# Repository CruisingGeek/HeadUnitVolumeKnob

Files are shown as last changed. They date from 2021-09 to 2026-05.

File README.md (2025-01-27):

# HeadUnitVolumeKnob
Putting this Arduino module between your aftermarket Android head unit with a rotary encoder allows volume control via the knob. Requires 2 n-channel MOSFETs to be driven from the Arduino Pro Micro

## Hardware
This code has been written to run on an Arduino Pro Micro. It should be easy to port it to other Arduino boards.

## Dependencies
This code depends on the CruisingGeekCommon library. You can find that library here: https://github.com/CruisingGeek/CruisingGeekCommon
Unpack that library into your Arduino libraries folder.

This code also depends on a 3rd party RotoryEncoder library you can find here: https://github.com/mathertel/RotaryEncoder
Unpack this into your libraries folder as well.

## MOSFET board
If you are building this project and would like the mosfet board to switch the two external resistors, please contact me @ CruisingGeek@gmail.com

## Wiring Diagrams
The following are wiring diagrams using both the MOSFET board and for generic MOSFETs

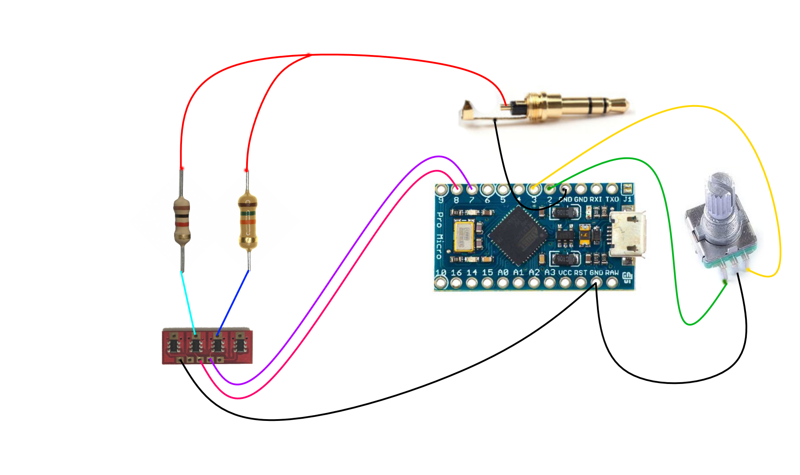
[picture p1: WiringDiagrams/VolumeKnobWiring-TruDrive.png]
Wiring diagram with TruDrive

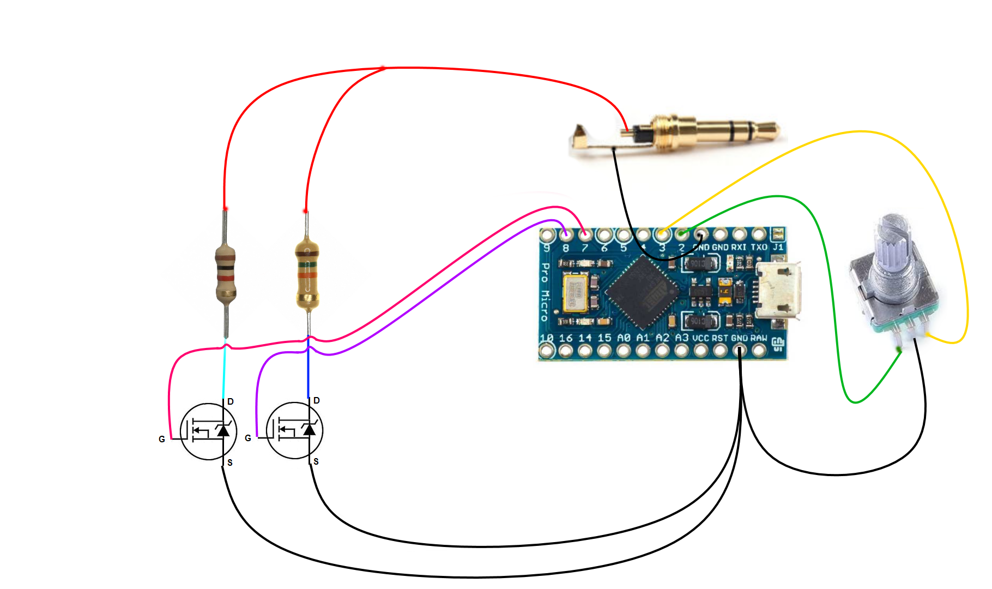
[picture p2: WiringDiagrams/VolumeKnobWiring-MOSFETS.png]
Wiring diagram with TruDrive


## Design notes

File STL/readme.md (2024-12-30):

#STL files for Atoto install
These files are the ones I used to install the Atoto S7 into my LP 560-4. It might work for other Audi cars of the 2000s era.

Use at your own risk; I'm not responsible for any issues that happen due to using these files.

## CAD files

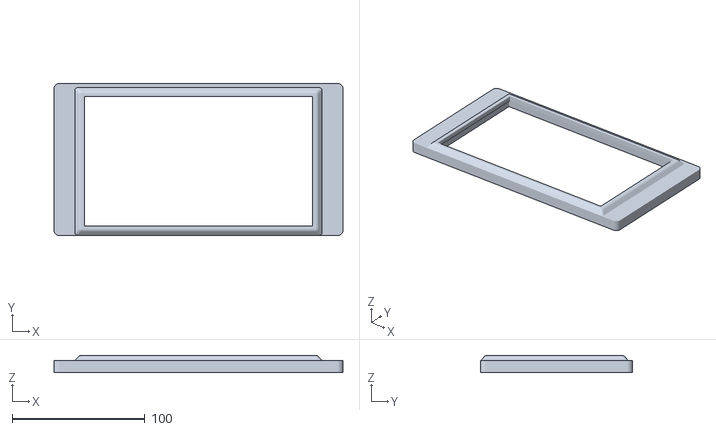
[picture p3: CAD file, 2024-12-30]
STL/Frame Full.stl
217.6 x 114.6 x 13.0

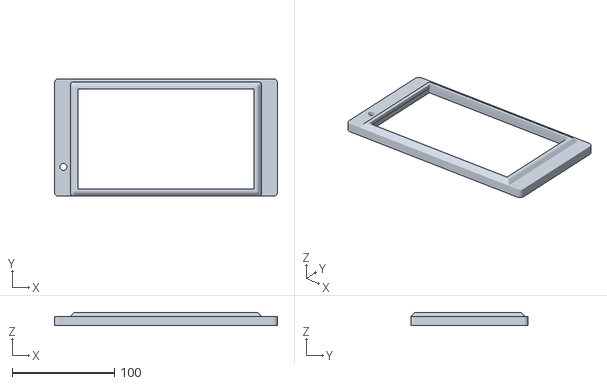
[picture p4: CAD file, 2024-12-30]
STL/Frame Full with Volume Mount.stl
217.6 x 114.6 x 13.0

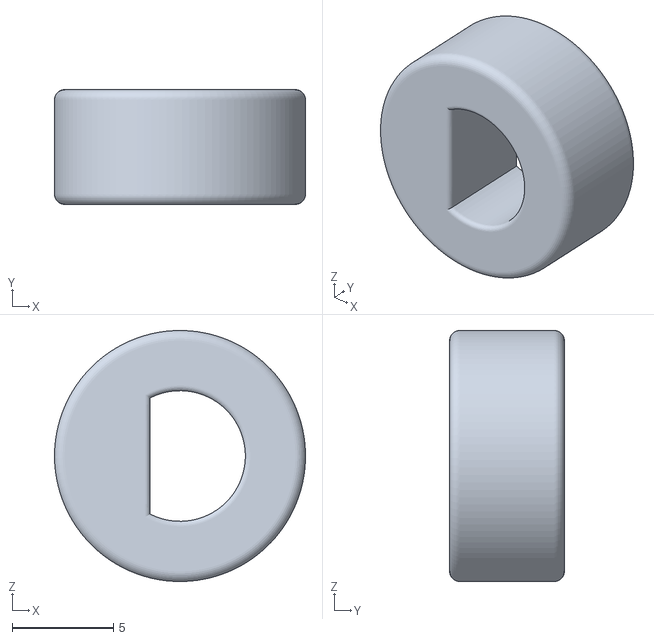
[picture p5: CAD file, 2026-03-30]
STL/Knob-StarToDShaft_revB.stl
12.4 x 5.67 x 12.4

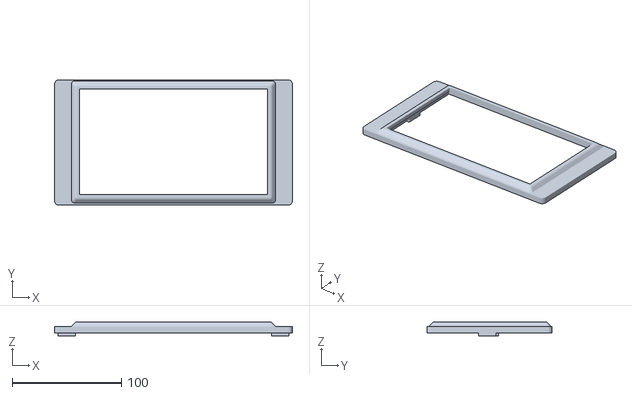
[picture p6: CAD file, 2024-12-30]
STL/Frame Slim.stl
217.6 x 114.6 x 13.0

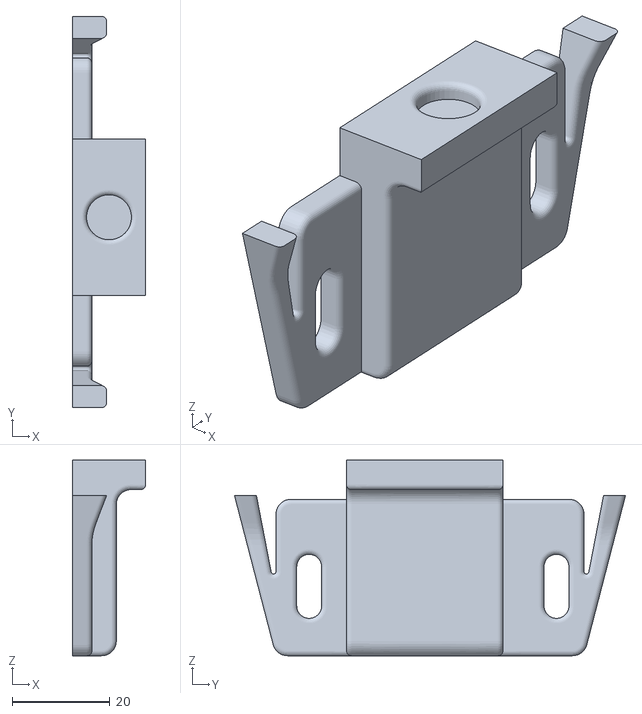
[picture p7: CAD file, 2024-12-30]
STL/Bracket R.stl
15.0 x 80.0 x 40.0

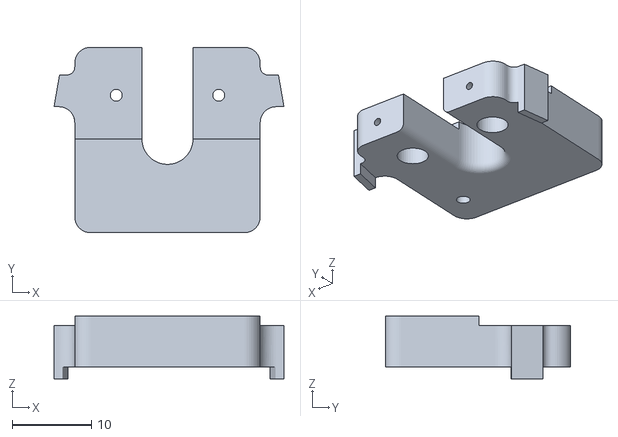
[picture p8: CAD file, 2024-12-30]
STL/Atoto Camera Adapter.stl
29.0 x 23.4 x 7.90

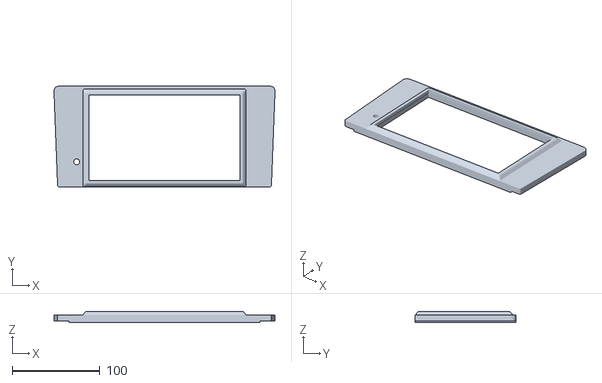
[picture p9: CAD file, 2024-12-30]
STL/Frame ALL with Volume.stl
252.1 x 115.1 x 13.0

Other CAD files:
STL/Bracket R Rev 4.stl
STL/Bracket R Rev 3.stl

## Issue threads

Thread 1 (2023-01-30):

Wiring questions

antlaranjeira, 2023-01-30:
- So the arduino will be feed in Vcc with 5v? And this circuit work all with 5v?
- Can I use a mosfet like 2N7000 - N-channel MOSFET?
- Wich resistors you used?

Thanks!

CruisingGeek, 2023-12-27:
1. Yes the arduino needs to be feed 5v, as it cannot run on power higher than 5v.
2. The 2N7000 should work as there isn't much current being drawn through the circuit so 200mA *SHOULD* be enough, though I never bothered to test the head unit to see how much it is actually pulling. Since it is only pulling that current for a fraction of a second I doubt it would fry the 200mA mosfet.
3. I forget the detailed values of the resistors I used, I just grabbed two from my parts bin that were between 1000ohm and 10,000 ohm. like a 2k for one and 3k for the other would be totally fine

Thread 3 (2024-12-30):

Compilation error: Encoder.h: No such file or directory

chrisbird83, 2024-12-30:
It appears as though encoder.h is missing. Could you assist?

Compilation error: Encoder.h: No such file or directory

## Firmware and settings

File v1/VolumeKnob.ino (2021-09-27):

#include "Arduino.h"
#include <Encoder.h>
#include <Stopwatch.h>

// ------------------------------------------------------------------------------------
// CONSTANTS
// ------------------------------------------------------------------------------------
// Uncomment this line to see debugging info
// #define SERIAL_DEBUG

// Define these as the physical pins that the encoder is attached to.
const uint8_t ENCODER_PIN_A = 7;
const uint8_t ENCODER_PIN_B = 8;

// Define these as the digital output pins in which the two N-channel MOSFETS connect.
const uint8_t MOSFET_DECREASING = 3;
const uint8_t MOSFET_INCREASING = 2;

// Define the test pin. Setting this pin to GND will put the device in test mode which
// sends the signal for the extended hold time, allowing you to configure the device via
// the android SwC app.
const uint8_t TEST_PIN = 15;

// Length of time in milliseconds to hold the moseft open simulating a human touch.
//
// If this value is too short, the head unit will not register a simulated button press
// by an external user. If the value is too long, this program could miss increments if
// the person is spinning the knob rapidly.
const uint32_t MOSFET_HOLD_MS = 100;
const uint32_t MOSFET_HOLD_LOW_MS = 4;

// Length of time in milliseconds to wait before polling the encoder to see if the
// state changed.
const uint32_t ENCODER_READ_MS = 1;

// Length in time in milliseconds that MOSFET is held when in test mode.
const uint32_t MOSFET_HOLD_EXTENDED_MS = 4000;
// ------------------------------------------------------------------------------------


// ------------------------------------------------------------------------------------
// Enums
// ------------------------------------------------------------------------------------
enum InternalState : uint8_t
{
    Off,
    Decreasing,
    Increasing,
    HoldLow,
};
// ------------------------------------------------------------------------------------


// ------------------------------------------------------------------------------------
// Variables
// ------------------------------------------------------------------------------------
// Encoder Variable; this does the heavy lifting to read the encoder values and update positions.
Encoder volumeKnob(ENCODER_PIN_A, ENCODER_PIN_B);

// Stopwatch variables to trigger turning off the MOSFETs and checking the encoder
Stopwatch encoderStopwatch;
Stopwatch mosfetStopwatch;
Stopwatch holdLowStopwatch;

// This stores the previous encoder value to see if the value has changed.
long previousEncoderValue = 0;

// Keeps track of when the MOSFETS need to be shut off.
InternalState state = InternalState::Off;

uint32_t lengthToHold;

long count = 0;
// ------------------------------------------------------------------------------------


// ------------------------------------------------------------------------------------
// Arduino Methods
// ------------------------------------------------------------------------------------
void setup()
{
    #ifdef SERIAL_DEBUG
    {
        Serial.begin(9600);
    }
    #endif // SERIAL_DEBUG

    pinMode(MOSFET_DECREASING, OUTPUT);
    pinMode(MOSFET_INCREASING, OUTPUT);
    pinMode(TEST_PIN, INPUT_PULLUP);
    digitalWrite(MOSFET_DECREASING, LOW);
    digitalWrite(MOSFET_INCREASING, LOW);

    encoderStopwatch.Start();
    mosfetStopwatch.Start();

    lengthToHold = MOSFET_HOLD_MS;
}

void loop()
{
    encoderStopwatch.Update();

    if (state == InternalState::Decreasing || state == InternalState::Increasing)
    {
        mosfetStopwatch.Update();
    }
    else
    {
        mosfetStopwatch.Reset();
    }

    if (state == InternalState::HoldLow)
    {
        holdLowStopwatch.Update();
    }
    else
    {
        holdLowStopwatch.Reset();
    }

    //if (encoderStopwatch.HasElapsed(ENCODER_READ_MS))
    {
        CheckForRotaryChange();
        encoderStopwatch.Reset();
    }

    if ((state == InternalState::Increasing || state == InternalState::Decreasing)
         && mosfetStopwatch.HasElapsed(lengthToHold))
    {
        HandleTurnOffMosfets();
        mosfetStopwatch.Reset();
        uint32_t testPinVal = digitalRead(TEST_PIN);
        lengthToHold = testPinVal == LOW ? MOSFET_HOLD_EXTENDED_MS : MOSFET_HOLD_MS;
    }

    if (state == InternalState::HoldLow && holdLowStopwatch.HasElapsed(MOSFET_HOLD_LOW_MS))
    {
        state = count == 0
            ? InternalState::Off
            : count > 0
                ? InternalState::Increasing
                : InternalState::Decreasing;
        
        if (state != InternalState::Off)
        {
            uint8_t pin = state == InternalState::Decreasing ? MOSFET_DECREASING : MOSFET_INCREASING;
            digitalWrite(pin, HIGH);
        }
    }
}
// ------------------------------------------------------------------------------------


// ------------------------------------------------------------------------------------
// Private methods
// ------------------------------------------------------------------------------------
void CheckForRotaryChange()
{
    long currentValue = volumeKnob.read();

    if (currentValue > previousEncoderValue && state != InternalState::Decreasing)
    {
        HandleKnobChange(InternalState::Decreasing);
    }
    else if (currentValue < previousEncoderValue && state != InternalState::Increasing)
    {
        HandleKnobChange(InternalState::Increasing);
    }

    previousEncoderValue = currentValue;
}

void HandleKnobChange(InternalState newState)
{
    #ifdef SERIAL_DEBUG
    {
        Serial.print("Handling ");
        Serial.println(newState == InternalState::Decreasing ? "Decreasing" : "Increasing");
    }
    #endif // SERIAL_DEBUG

    if (count == 0)
    {
        uint8_t pin = newState == InternalState::Decreasing ? MOSFET_DECREASING : MOSFET_INCREASING;
        digitalWrite(pin, HIGH);
    }
    count += newState == InternalState::Decreasing ? -1 : 1;
    state = newState;
}

void HandleTurnOffMosfets()
{
    #ifdef SERIAL_DEBUG
    {
        Serial.println("Turning off mosfets");
    }
    #endif // SERIAL_DEBUG

    count += state == InternalState::Increasing ? -1 : 1;
    state = InternalState::HoldLow;
    digitalWrite(MOSFET_DECREASING, LOW);
    digitalWrite(MOSFET_INCREASING, LOW);
}
// ------------------------------------------------------------------------------------

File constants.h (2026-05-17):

#ifndef __CruisingGeek_Constants_H__
#define __CruisingGeek_Constants_H__

// --------------------------------------------------------------------------------------------------------------------
// PINS
// --------------------------------------------------------------------------------------------------------------------
#if defined(ARDUINO_AVR_UNO)
    #define VOLUME_KNOB_SHIELD 1

    // Define these as the physical pins that the encoder is attached to.
    const uint8_t ENCODER_PIN_A = 9;
    const uint8_t ENCODER_PIN_B = 8;

    // Define these as the digital output pins in which the two N-channel MOSFETS connect.
    const uint8_t MOSFET_DECREASING_PIN = 11;
    const uint8_t MOSFET_INCREASING_PIN = 12;
    const uint8_t MOSFET_BUTTON_PIN = 10;

    //
    // Define the test pin. Setting this pin to GND will put the device in test mode which sends the signal for the
    // extended hold time, allowing you to configure the device via the android SwC app.
    //
    const uint8_t TEST_PIN = 2;

    //
    // Define the Mode pin. Settings this pin to GND indicates that the device should be ran in the NEC digital mode,
    // which supports Kenwood and JVC head units.
    //
    const uint8_t MODE_PIN = 3;

    //
    // For testing convenience, have the neighboring pin to the TEST_PIN and MODE_PIN output GND so a jumper can be
    // used on the header to turn either of those on.
    //
    const uint8_t OUTPUT_GND_PIN = 4;

    //
    // Define the digital output pin that drives the MOSFET for the digital communication protocol, used in Kenwood
    // and select JVC models.
    //
    // For V2 pcbs, the MOSFET is shared but the user can select the correct resistor from the DIP switch.
    //
    // For V1.1 pcbs, there is only two available so we will reuse the increasing one from the analog output. This
    // means that the R1 resistor needs to be swapped though with one more in the 100 ohm range.
    //
    const uint8_t MOSFET_DIGITAL_PIN = 11;

    //
    // Knob button needs to be read by the CPU to handle the digital version, and its output sent to a transistor for
    // the analog version.
    //
    // For 1.x boards, this button is ONLY supported when using the digital headunit, aka Kenwood/JVC. That's because
    // there is no corresponding MOSFET to trigger the analog resistor. On 1.x boards when using the digital headunit
    // the wire for MUTE 1 needs to be moved directly to Pin 14, the PIN right above VIN on the rail with six inputs.
    //
    // For 2.x boards, just wire to the MUTE 1 and MUTE 2 pads as normal.
    //
    const uint8_t ENCODER_BUTTON_PIN = 14;
#else
    // Define these as the physical pins that the encoder is attached to.
    const uint8_t ENCODER_PIN_A = 2;
    const uint8_t ENCODER_PIN_B = 3;

    // Define these as the digital output pins in which the two N-channel MOSFETS connect.
    const uint8_t MOSFET_DECREASING_PIN = 8;
    const uint8_t MOSFET_INCREASING_PIN = 7;
    const uint8_t MOSFET_BUTTON_PIN = 9;

    // Define the test pin. Setting this pin to GND will put the device in test mode which
    // sends the signal for the extended hold time, allowing you to configure the device via
    // the android SwC app.
    const uint8_t TEST_PIN = 15;

    // Safe to reuse the normal volume MOSFET pin for the digital version.
    MOSFET_DIGITAL_PIN = 11;

    const uint8_t ENCODER_BUTTON_PIN = 5
#endif
// --------------------------------------------------------------------------------------------------------------------


// Uncomment this line to see debugging info
// #define SERIAL_DEBUG

// Set this to non-zero to have an initial start value for testing
#define INITIAL_START 0

// Length of time in milliseconds (ms) to hold the mosfet open simulating a human touch for the analog driver.
//
// If this value is too short, the head unit will not register a simulated button press by an external user. If the
// value is too long, this program could miss increments if the person is spinning the knob rapidly, and the input lag
// becomes too noticeable.
//
const uint32_t MOSFET_HOLD_MS = 60;
const uint32_t MOSFET_HOLD_LOW_MS = 60;

// Length of time in milliseconds (ms) between sending digital commands for the digital driver.
//
// If this value is too long, the volume turn will have too much lag and feel sluggish. If the value is too small,
// tuns on the knob could be missed since the program will spend too many cycles on sending the command as opposed to
// reading the knob input.
//
const uint32_t DIGITAL_COMMAND_PAUSE_MS = 2;

// Length of time in milliseconds to wait before polling the encoder to see if the
// state changed.
const uint32_t ENCODER_READ_MS = 1;

// Length in time in milliseconds that MOSFET is held when in test mode.
const uint32_t MOSFET_HOLD_EXTENDED_MS = 4000;

#endif  // __CruisingGeek_Constants_H__

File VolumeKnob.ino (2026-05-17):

// --------------------------------------------------------------------------------------------------------------------
// 
// Head Unit Volume Knob
// Scott DeBoer aka Cruising Geek
// 
// This project is used to interface a rotary encoder with aftermarket head units which have an SWC or remote control
// input.
//
// Updated 2026-April-14
// This now supports all three of the major classes of head units on the market.
//  1. Android head units with configurable resistor values (ie the original Atoto this project was made for).
//  2. Analog head units that have Panosonic style hard-coded resistor values (namely Pioneer and Sony).
//  3. Head units with a single Remote input which communicate with an NEC digital protocol (Kenwood, JVC).
// 
// It is possible that there are more subtypes of case 2 that are unknown and would not be supported, but since most
// customers that are not using and Android-based one are using Pioneer or Kenwood this covers most cases.
//
// By wiring the arduino and interfacing with the head unit, twisting the volume knob will allow the volume to be
// adjusted with the knob as opposed to using the buttons that most head units provide. Further, a single press on the
// rotary encoder will mute the head unit (for some Pioneer models it will do attenuation, which is a super low
// volume but not fully muted). Of course with the Android configurable ones you can configure it to anything desired.
//
// Update 2025-Oct-19
// Because most aftermarket head units continue to provide 5v to the USB even if the keyed ignition is turned off,
// it is necessary to run the Arduino Pro Micro with an external 5v buck module to prevent buffer overflow in the
// code, and to prevent battery drain in the car. Due to this, I've also added support for Arduino UNO boards, which
// already have a 5v buck module built-on. If you have the physical space using that board provides a bit cleaner
// wiring.
// 
// --------------------------------------------------------------------------------------------------------------------

#include "Arduino.h"

#include "constants.h"
#include "HeadUnitDriver.h"

// --------------------------------------------------------------------------------------------------------------------
// LIBRARIES
// 
// These library includes are libraries you need to download and then copy into your /arduino/Libraries directory.
// --------------------------------------------------------------------------------------------------------------------

// Library location: https://github.com/mathertel/RotaryEncoder
#include <RotaryEncoder.h>
// Library location: https://github.com/CruisingGeek/CruisingGeekCommon
#include <Stopwatch.h>
// Library location: https://github.com/CruisingGeek/CruisingGeekCommon
#include <Button.h>
// --------------------------------------------------------------------------------------------------------------------


// --------------------------------------------------------------------------------------------------------------------
// Variables
// --------------------------------------------------------------------------------------------------------------------

//
// Construct the driver for both the digital and analog version. While it does waste a bit of space this will ensure
// that selection can be done easily. In the future, if space becomes an issue these could be loaded in via memory
// allocation.
//

DigitalHeadUnitDriver digitalDriver(
    MOSFET_DIGITAL_PIN,
    DIGITAL_COMMAND_PAUSE_MS,
    // Mute is the best option here, as play/pause and next track are context dependent in most Kenwood head units,
    // ie on the home screen do nothing, and in the radio do not what you'd expect. Mute on the other hand always
    // mutes.
    KenwoodCommand::Mute);

AnalogHeadUnitDriver analogDriver(MOSFET_INCREASING_PIN, MOSFET_DECREASING_PIN, MOSFET_BUTTON_PIN, TEST_PIN);

// Encoder Variable; this does the heavy lifting to read the encoder values and update positions.
RotaryEncoder volumeKnob(ENCODER_PIN_A, ENCODER_PIN_B, RotaryEncoder::LatchMode::FOUR3);

// Button attached to the rotary encoder.
Button knobButton(
    ENCODER_BUTTON_PIN,
    ButtonType::Momentary,
    ButtonPolarity::ActiveLow,
    1000, /* 1000ms */
    true /* usePullup */);

//
// HeadUnitDriver. The specific instance is currently set by firmware modification; in the future the board could have
// a dip switch or jumper to set this by the customer without firmware loading.
//
IHeadUnitDriver *headUnitDriver;

// Keeps track of the encoder's virtual position, which is the number of clicks forward minus number of clicks
// backwards since startup.
long previousPosition;
// --------------------------------------------------------------------------------------------------------------------


// --------------------------------------------------------------------------------------------------------------------
// Arduino Methods
// --------------------------------------------------------------------------------------------------------------------
void setup()
{
    #ifdef SERIAL_DEBUG
    {
        Serial.begin(115200);
    }
    #endif // SERIAL_DEBUG

    pinMode(MOSFET_DECREASING_PIN, OUTPUT);
    pinMode(MOSFET_INCREASING_PIN, OUTPUT);
    pinMode(MOSFET_BUTTON_PIN, OUTPUT);
    pinMode(TEST_PIN, INPUT_PULLUP);
    pinMode(MODE_PIN, INPUT_PULLUP);
    pinMode(OUTPUT_GND_PIN, OUTPUT);

    digitalWrite(MOSFET_DECREASING_PIN, LOW);
    digitalWrite(MOSFET_INCREASING_PIN, LOW);
    digitalWrite(MOSFET_BUTTON_PIN, LOW);
    digitalWrite(OUTPUT_GND_PIN, LOW);

    // Need a small delay here to ensure MODE_PIN is setup correctly.
    delay(10);

    // Select the correct head unit driver based on the DIP switch, and select it accordingly.
    //
    auto mode = digitalRead(MODE_PIN);

    headUnitDriver = mode == LOW
        ? (IHeadUnitDriver*)&digitalDriver
        : (IHeadUnitDriver*)&analogDriver;

    headUnitDriver->StartDriver();
}

void loop()
{
    volumeKnob.tick();
    headUnitDriver->UpdateCounters();

    {
        // Rotary encoder input checks.
        CheckForRotaryChange();
        CheckForRotaryPress();
    }

    headUnitDriver->RunIteration();
}
// --------------------------------------------------------------------------------------------------------------------
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

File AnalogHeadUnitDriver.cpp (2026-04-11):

#include "HeadUnitDriver.h"

#include <Stopwatch.h>

// --------------------------------------------------------------------------------------------------------------------
// Constructor
// --------------------------------------------------------------------------------------------------------------------
AnalogHeadUnitDriver::AnalogHeadUnitDriver(
    uint8_t increasingPin,
    uint8_t decreasingPin,
    uint8_t buttonPin,
    uint8_t testPin
)
    : _iPin(increasingPin)
    , _dPin(decreasingPin)
    , _bPin(buttonPin)
    , _tPin(testPin)
    , _state(InternalState::Off)
    , _lengthToHold(MOSFET_HOLD_MS)
    , _count(0)
{
    _mosfetStopwatch = new Stopwatch();
    _holdLowStopwatch = new Stopwatch();
}
// --------------------------------------------------------------------------------------------------------------------


// --------------------------------------------------------------------------------------------------------------------
// IHeadUnitDriver interface methods
// --------------------------------------------------------------------------------------------------------------------
void AnalogHeadUnitDriver::StartDriver()
{
    _mosfetStopwatch->Start();

    #if INITIAL_START != 0
    {
        count = 0;
        state = InternalState::Off;
    }
    #endif  // INITIAL_START != 0
}

void AnalogHeadUnitDriver::UpdateCounters()
{
    if (_state == InternalState::Decreasing
        || _state == InternalState::Increasing
        || _state == InternalState::ButtonPress)
    {
        _mosfetStopwatch->Update();
    }
    else
    {
        _mosfetStopwatch->Reset();
    }

    if (_state == InternalState::HoldLow)
    {
        _holdLowStopwatch->Update();
    }
    else
    {
        _holdLowStopwatch->Reset();
    }
}

void AnalogHeadUnitDriver::RunIteration()
{
    if ((
            _state == InternalState::Increasing
            || _state == InternalState::Decreasing
            || _state == InternalState::ButtonPress
        )
        && _mosfetStopwatch->HasElapsed(_lengthToHold))
    {
        _count += _state == InternalState::ButtonPress
            ? 0
            : _state == InternalState::Increasing ? -1 : 1;
        _state = InternalState::HoldLow;

        TurnOffMosfets();
        UpdateLengthToHold();
    }

    else if (_state == InternalState::HoldLow && _holdLowStopwatch->HasElapsed(MOSFET_HOLD_LOW_MS))
    {
        _state = _count == 0
            ? InternalState::Off
            : _count > 0
                ? InternalState::Increasing
                : InternalState::Decreasing;
        
        if (_state != InternalState::Off)
        {
            uint8_t pin = _state == InternalState::Decreasing ? _dPin : _iPin;
            digitalWrite(pin, HIGH);
        }
    }
}

void AnalogHeadUnitDriver::HandleKnobChange(int delta, InternalState newState)
{
    if (_count == 0)
    {
        if (_state == InternalState::Off)
        {
            uint8_t pin = newState == InternalState::Decreasing ? _dPin : _iPin;
            digitalWrite(pin, HIGH);
        }

        // TODO test this.
        _state = newState;
    }

    _count += newState == InternalState::Increasing ? delta : -delta;
}

void AnalogHeadUnitDriver::HandleKnobPressed()
{
    _state = InternalState::ButtonPress;
    TurnOffMosfets();
    digitalWrite(_bPin, HIGH);
    _mosfetStopwatch->Reset();
}
// --------------------------------------------------------------------------------------------------------------------


// --------------------------------------------------------------------------------------------------------------------
// Private methods
// --------------------------------------------------------------------------------------------------------------------
void AnalogHeadUnitDriver::TurnOffMosfets()
{
    #ifdef SERIAL_DEBUG
    {
        Serial.println("Turning off mosfets");
    }
    #endif // SERIAL_DEBUG

    digitalWrite(_dPin, LOW);
    digitalWrite(_iPin, LOW);
    digitalWrite(_bPin, LOW);
}

void AnalogHeadUnitDriver::UpdateLengthToHold()
{
    uint32_t testPinVal = digitalRead(_tPin);
    _lengthToHold = testPinVal == LOW ? MOSFET_HOLD_EXTENDED_MS : MOSFET_HOLD_MS;
}
// --------------------------------------------------------------------------------------------------------------------

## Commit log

2021-10-11 Update README.md
    Add wiring diagrams inline
2024-12-30 Add STLs used for my project
    [Atoto Camera Adapter.stl, Bracket R Rev 2.stl, Bracket R Rev 3.stl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]
2025-10-19 Update .vscode settings for my new Windows 11 install, and for use with Arduino IDE 2.x, specifically for use with the Arduino CLI.
2026-03-30 Add new STL file for and adapter that allows using a star-shaped knob on a D-shaft encoder
    [Knob-StarToDShaft_revB.stl]
2026-03-30 Support for Kenwood/one-wire digital headuint communication
    This is a large change that brings on support for the headunits that use a digital protocol for remote control buttons, namely Kenwood and JVC. These head units have a single wire called remote input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
    To support this change, the main program is now refactored to call an IHeadUnitDriver instance, which is an interface that abstracts the communication to the head uint. There are now two implementati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
    HeadUnitDriver.h
    -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
2026-03-30 Mute functionality
    Utilizing the new Cruising Geek common library revision which allows constructing a button with the built-in pullup resistor, implement the mute functionality
2026-04-01 Create PulseGenerator class that is timer based, update DigitalHeadUnitDriver to use this singleton to pulse as opposed to using the inline delay version
2026-04-01 Fix bug with digital driver that second command would come in and override the first command. This is because the DigitalHeadUnitDriver needed to know when the PulseGenerator was busy, and only wait 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
    Also cleaned up the main program, removing the unneeded stopwatch completely.
    [PulseGenerator.cpp, VolumeKnob.ino]
2026-04-11 Update AnalogHeadUnitDriver to support reading the button press and sending mute via a transistor.
    Also updated the constants for the MOSFET times as the Pioneer head unit seems to have a bit more delay when reading the transistor push times than the Android based ones did.
2026-04-12 Reverse the pins and encoder check so that the code handles increasing as volume up, decreasing as volume down with desired encoder wiring.
    [VolumeKnob.ino, constants.h]
2026-04-12 From two changes ago, the pins were reversed so the code would match. This change ensures that the increasing MOSFET is the one that is used for the digital driver.
    For v1.x boards, its recommended to just swap both R1 and R2 (ones labeled 2.2k and 3.3k) to the 33-100 ohm resistor if using the digital board to avoid confusion. This ensures that for future boards the correct one is used as that will allow switching via a DIP switch without a code change.
    [constants.h]
2026-04-12 Actually last change not needed; effective reverse.
    [constants.h]
2026-04-15 Select the correct driver based on the values selected from the DIP switch.
    [VolumeKnob.ino, constants.h]
2026-04-15 Add a comment for the TimerOne library location
2026-05-17 Flip encoderA and encoderB pins to match the prefered wiring that enc- goes to the left most pin.
    [constants.h]
2026-05-17 Add a small delay before reading the mode to ensure its pin state was setup correctly.
    [VolumeKnob.ino]
2026-05-17 Stop tracking arduino.json
2026-05-17 Specify the arduino.json exact path
